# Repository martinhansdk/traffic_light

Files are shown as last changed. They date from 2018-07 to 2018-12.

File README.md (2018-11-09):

Toy traffic light
=================



Firmware for a toy traffic light with intrafred communication between the units.

Features
--------

* The master light sends the timing to the slaves so independent lights remain
  in sync
* Automatic mode follows a preprogrammed timing
* Manual mode allows controlling the light through a button press on the master

Electronics
-----------

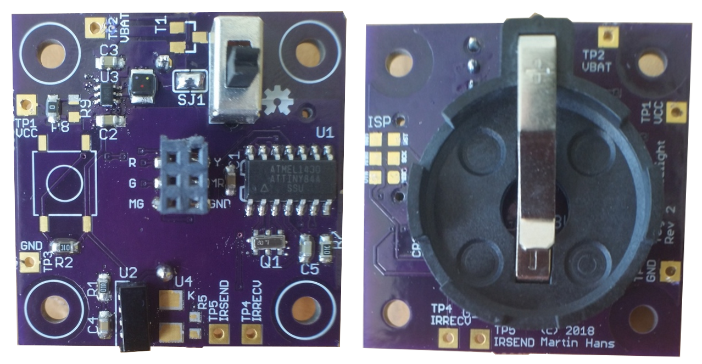
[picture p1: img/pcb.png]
MCU PCB


  * [schematic](pcb/MCU%20board_in_foot_v2.pdf)
  * [BOM](pcb/MCU%20board_in_foot_BOM_v2.html)
  * [EAGLE schematic](pcb/MCU%20board_in_foot_v2.sch)
  * [EAGLE layout](pcb/MCU%20board_in_foot_v2.brd)

The MCU board in the foot of the traffic light contains 

  * a 3V CR2032 battery 
  * an on/off button
  * a boost converter circuit that brings the voltage up to 3.3V
  * an ATTINY84 MCU running at 4 MHz
  * a push button (master only)
  * an IR LED (master only)
  * an IR receive module (slave only)
  * a connector for connecting to the LED board
  * a few test points
  * pads for accessing the ISP port of the MCU using pogo pins

Errata for this version of the board:

  * IRSEND on wrong gpio pin, should be on PB2
  * The IR receiver module has the wrong footprint - it should be the version that looks up
  * The boost converter does not start from CR2032, but works from alkaline
  * Some silk screen is too small
  * Difficult to remove battery from battery holder
  * ISP pins are hard to use. An edge connector would be better.

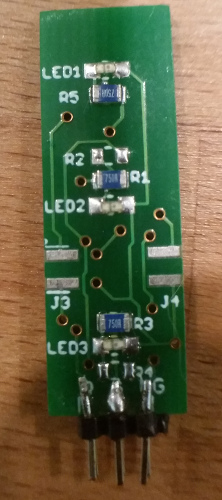
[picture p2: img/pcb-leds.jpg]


  * [schematic](pcb/LEDs_in_top.pdf)
  * [BOM](pcb/LEDs_in_top_BOM.html)
  * [EAGLE schematic](pcb/LEDs_in_top.sch)
  * [EAGLE layout](pcb/LEDs_in_top.brd)

The LED board of the traffic light contains

  * red, yellow and green LEDs with resistors
  * a connector for connecting to the MCU board
  * edge connector for adding another board with pedestrian lights or similar

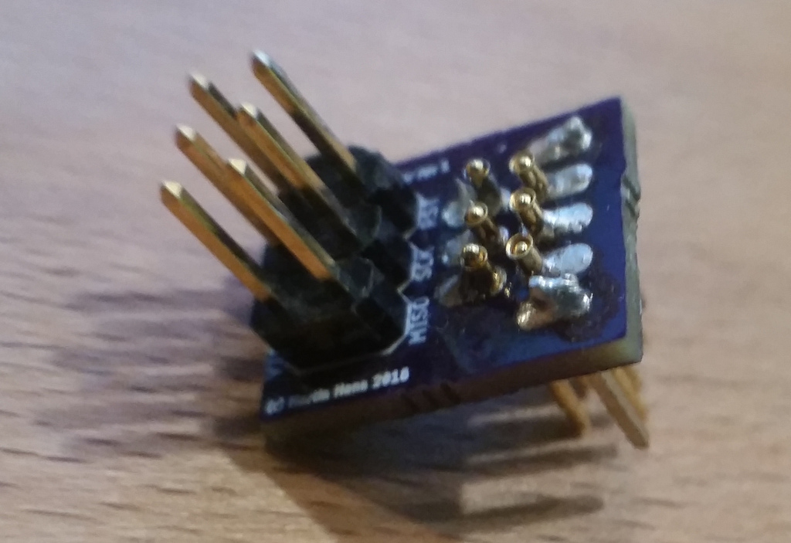
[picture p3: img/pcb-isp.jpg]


  * [schematic](pcb/pogo_pin_programmer_adapter.pdf)
  * [EAGLE schematic](pcb/pogo_pin_programmer_adapter.sch)
  * [EAGLE layout](pcb/pogo_pin_programmer_adapter.brd)

A special purpose pogo pin adapter board brings the footprint of the
ISP header down to a size that is small enough to fit the MCU
board. It also provides access to some debug pins.

This version does not work that well, so I'll probably find a better
solution for the next revision.

Firmware
========

The firmware is written in C.

 * Timer 0 triggers once every 1 ms and drives the light schedule
 * Timer 1 triggers once every 50us and is used by the IR receive code
 * hal/pins.h contains the macros for controlling the GPIO pins in an efficient yet readable manner

For IR communication it uses a library based on
https://github.com/shirriff/Arduino-IRremote. The source of the ATTINY C port
seems to have disappeared from the Internet, so I can't link to it.

The firmware is not feature complete yet. To do:

 * get the IR receive code working
 * implement manual mode
 * use button to select between different programs
 * autodetect master or slave mode
 * use sleep modes

Communication protocol
======================

The communication protocol is RC5 on a 36 kHz carrier frequency. An 18 bit word is sent every time:

 * `data[17]    =    1` : start bit
 * `data[16:10] = 0x5a` : command/address
 * `data[9]     = mode` : 1=manual mode, 0=automatic mode
 * `data[8:0]   = time` : unit is 0.5s

Firmware build instructions
===========================

To build the firmware on Ubuntu or Debian do the following:

    sudo apt-get install gcc-avr binutils-avr avr-libc avrdude
    git clone https://github.com/martinhansdk/traffic_light.git
    
Connect an AVR programmer such as an usbasp to the board. The
programmer has to be set to slow mode and 3.3V operation. Edit the
Makefile to change the programmer type if needed and run
    
    make clean
    make MASTER=1
    make fuse
    make flash
    
To program a slave run the above with `MASTER=0`.

To run the unittests

    make test
    
The unittests execute on the host machine.

Mechanics
=========

The mechanics have not been designed yet, but the traffic light will
be around 10 cm high. The following sketches are from the initial
brainstorming of the concept:

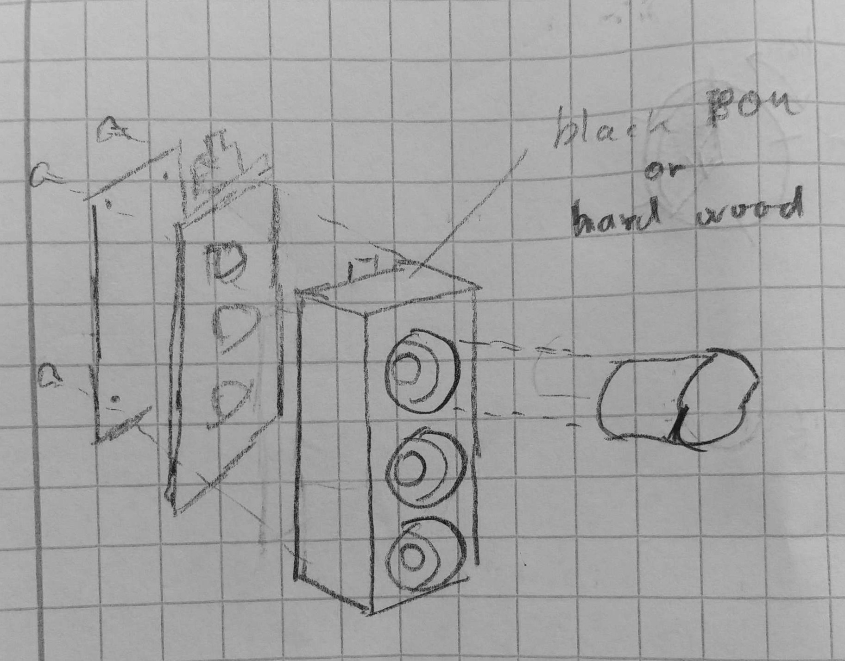
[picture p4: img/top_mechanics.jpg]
Sketch of the top mechanics


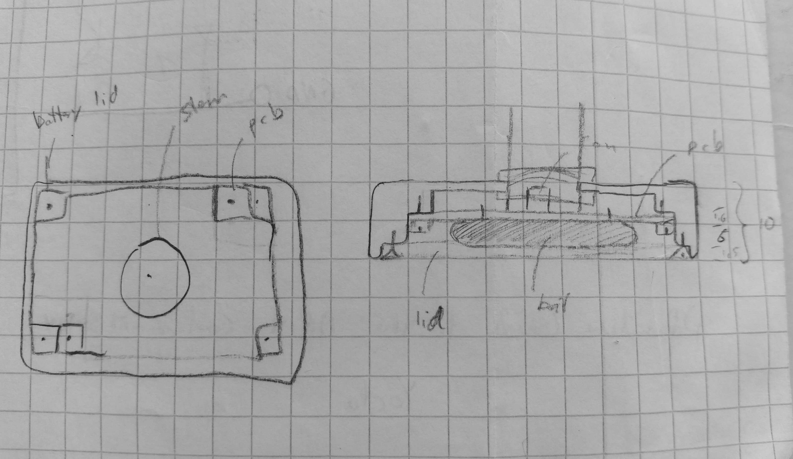
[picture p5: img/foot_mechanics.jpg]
Sketch of the foot mechanics


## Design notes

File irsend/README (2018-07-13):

This is a port of the sending part of the Arduino IRRemote library to
attiny44/attiny84/attiny45/attiny85. It is based on the version at
https://github.com/shirriff/Arduino-IRremote

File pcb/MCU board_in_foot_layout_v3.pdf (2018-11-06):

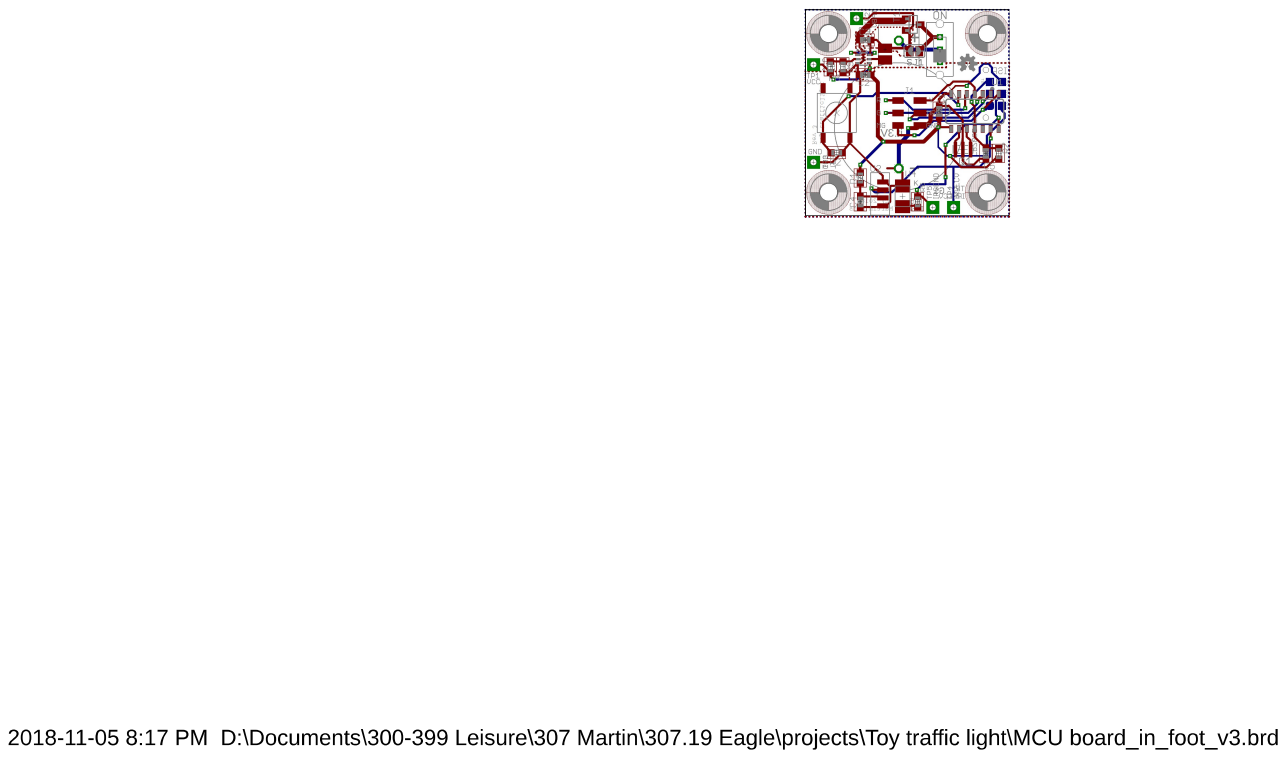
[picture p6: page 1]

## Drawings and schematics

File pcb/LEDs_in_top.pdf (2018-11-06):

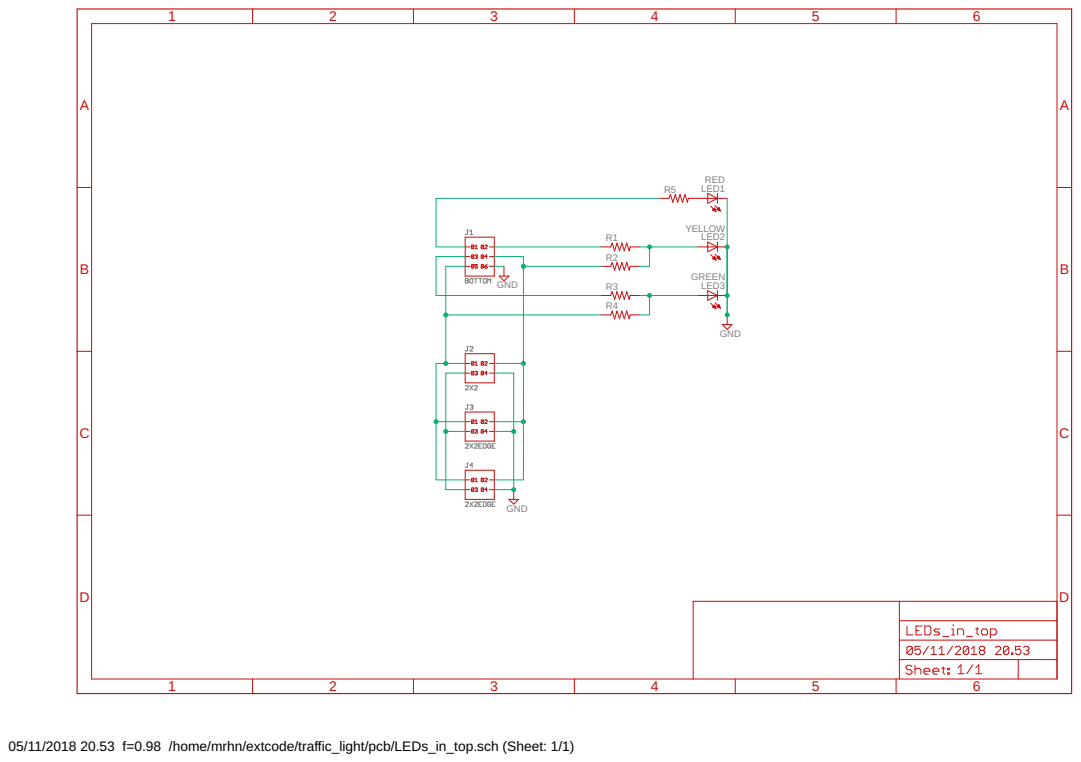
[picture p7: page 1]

05/11/2018 20.53 f=0.98 /home/mrhn/extcode/traffic_light/pcb/LEDs_in_top.sch (Sheet: 1/1)

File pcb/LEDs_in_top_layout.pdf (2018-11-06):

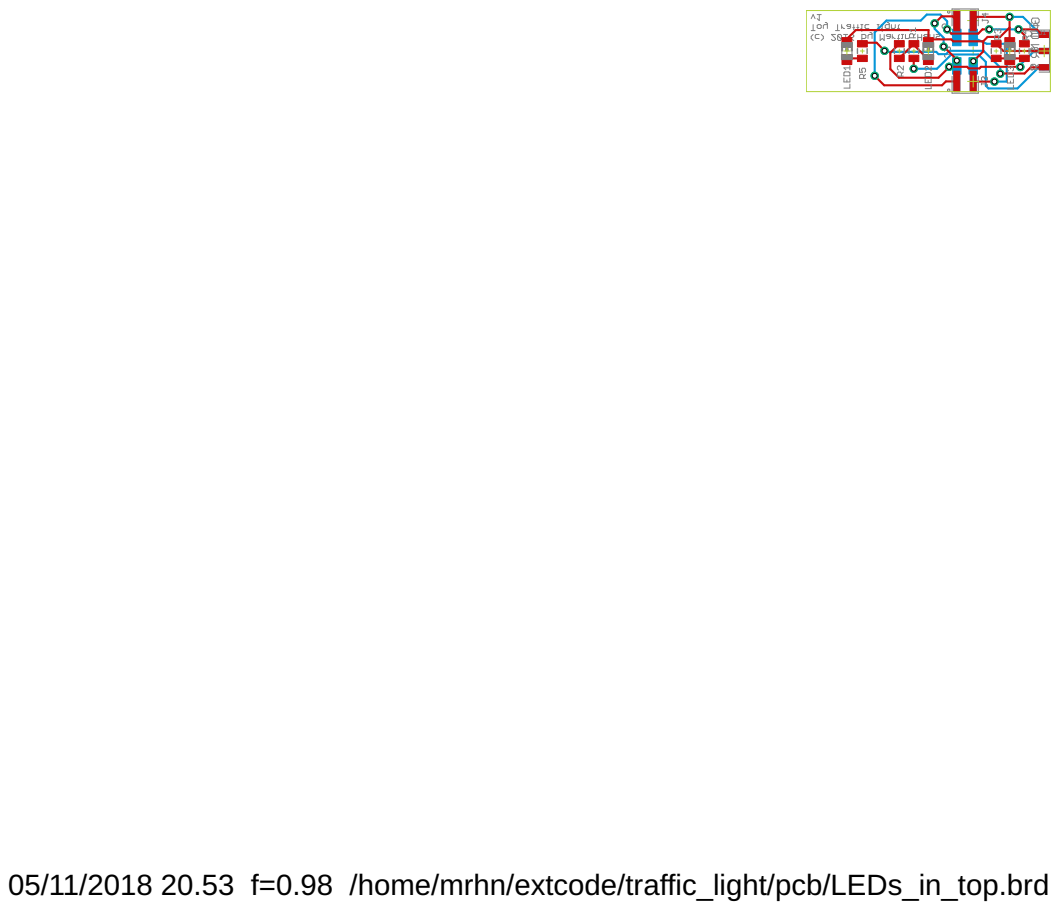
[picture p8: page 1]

05/11/2018 20.53 f=0.98 /home/mrhn/extcode/traffic_light/pcb/LEDs_in_top.brd

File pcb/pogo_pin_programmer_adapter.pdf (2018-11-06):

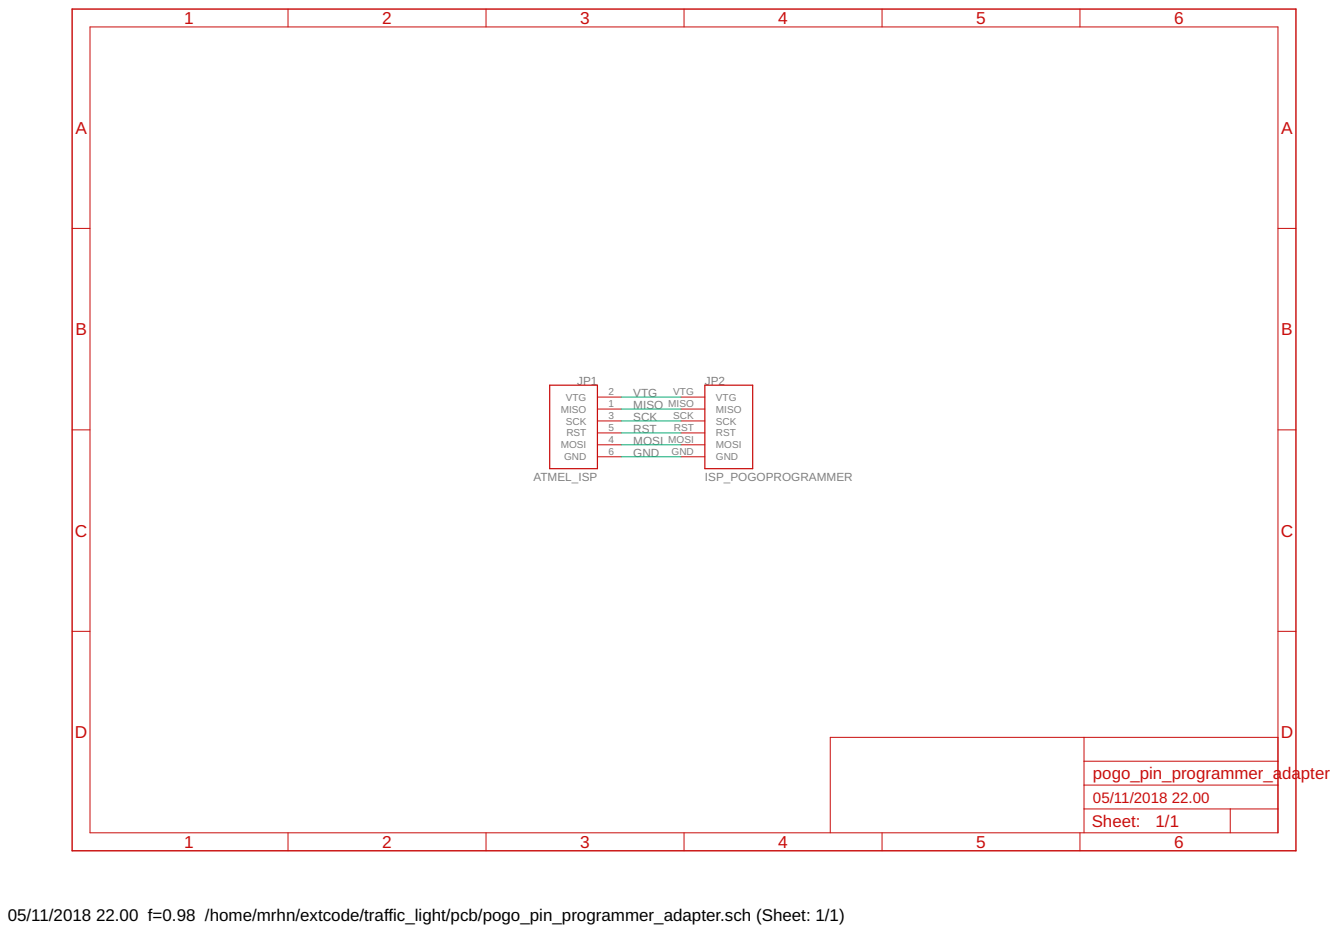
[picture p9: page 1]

05/11/2018 22.00 f=0.98 /home/mrhn/extcode/traffic_light/pcb/pogo_pin_programmer_adapter.sch (Sheet: 1/1)

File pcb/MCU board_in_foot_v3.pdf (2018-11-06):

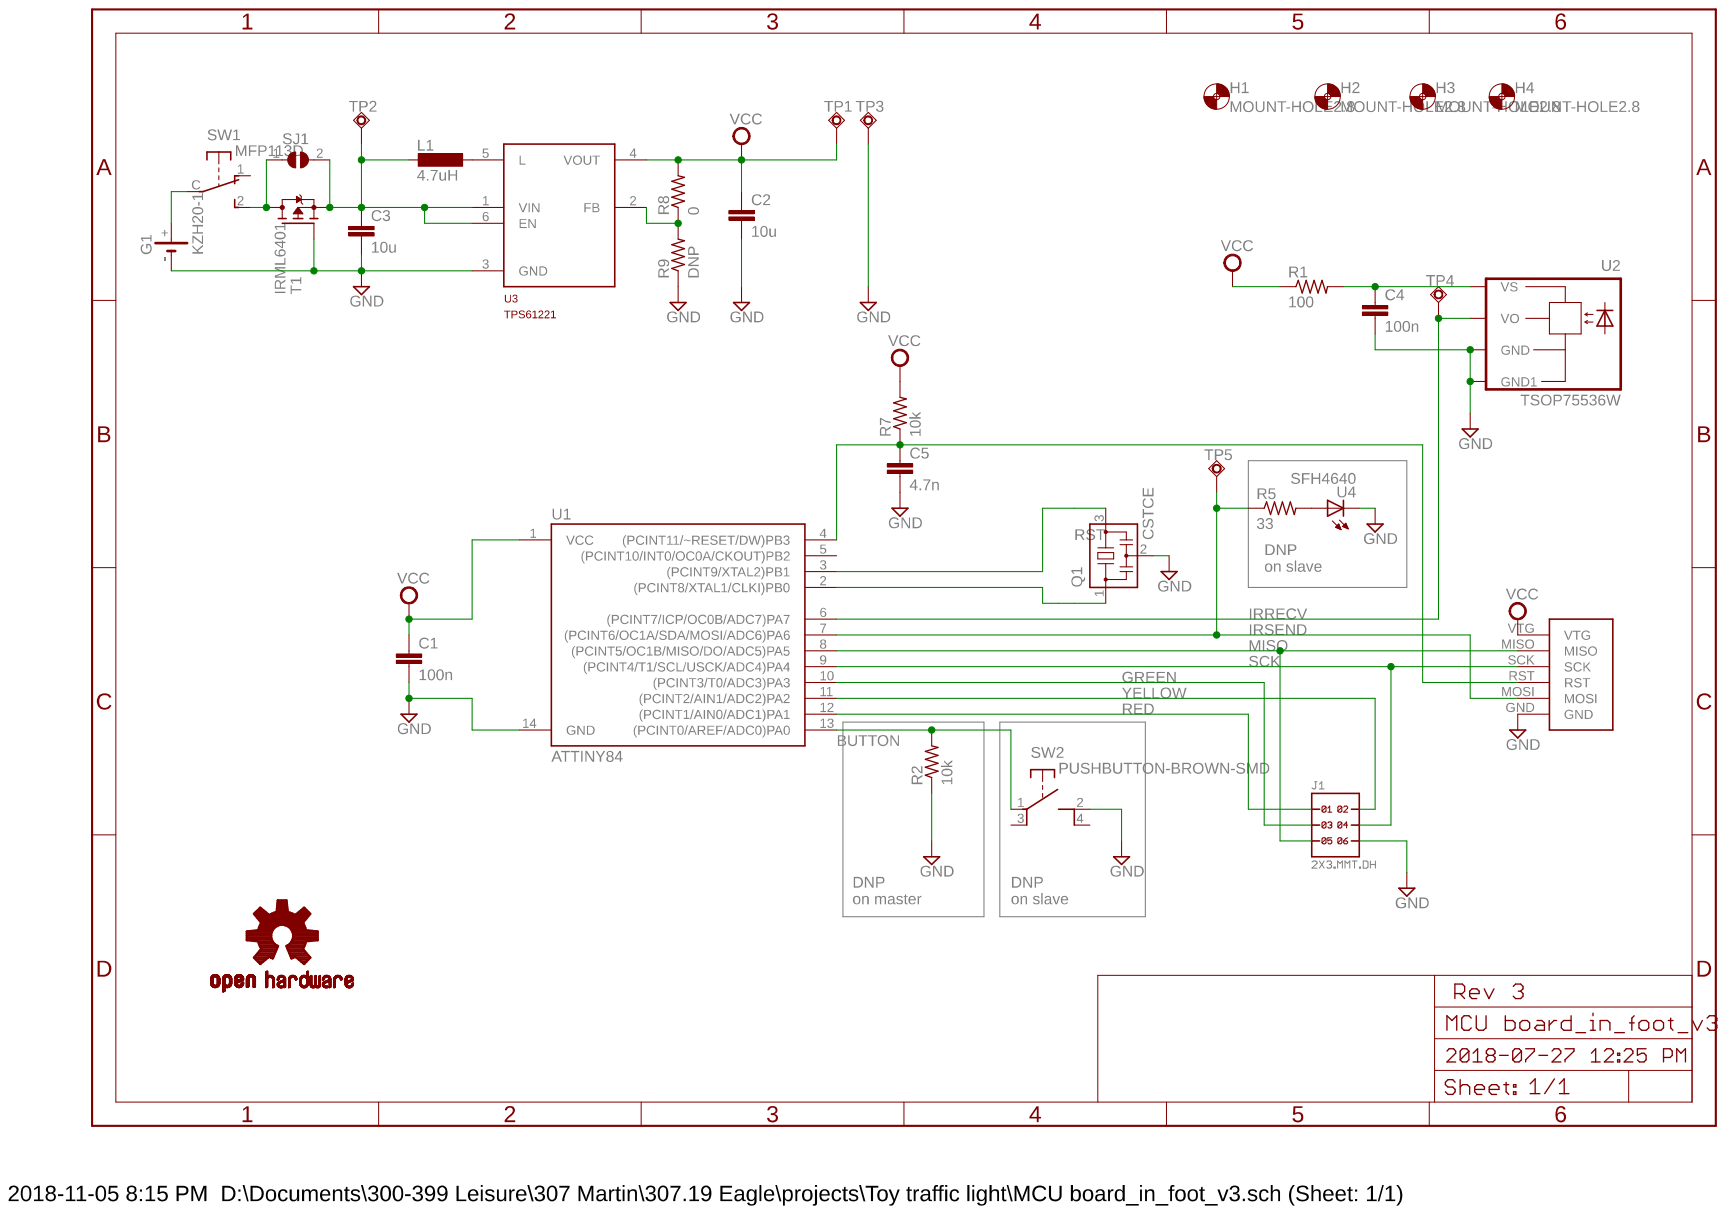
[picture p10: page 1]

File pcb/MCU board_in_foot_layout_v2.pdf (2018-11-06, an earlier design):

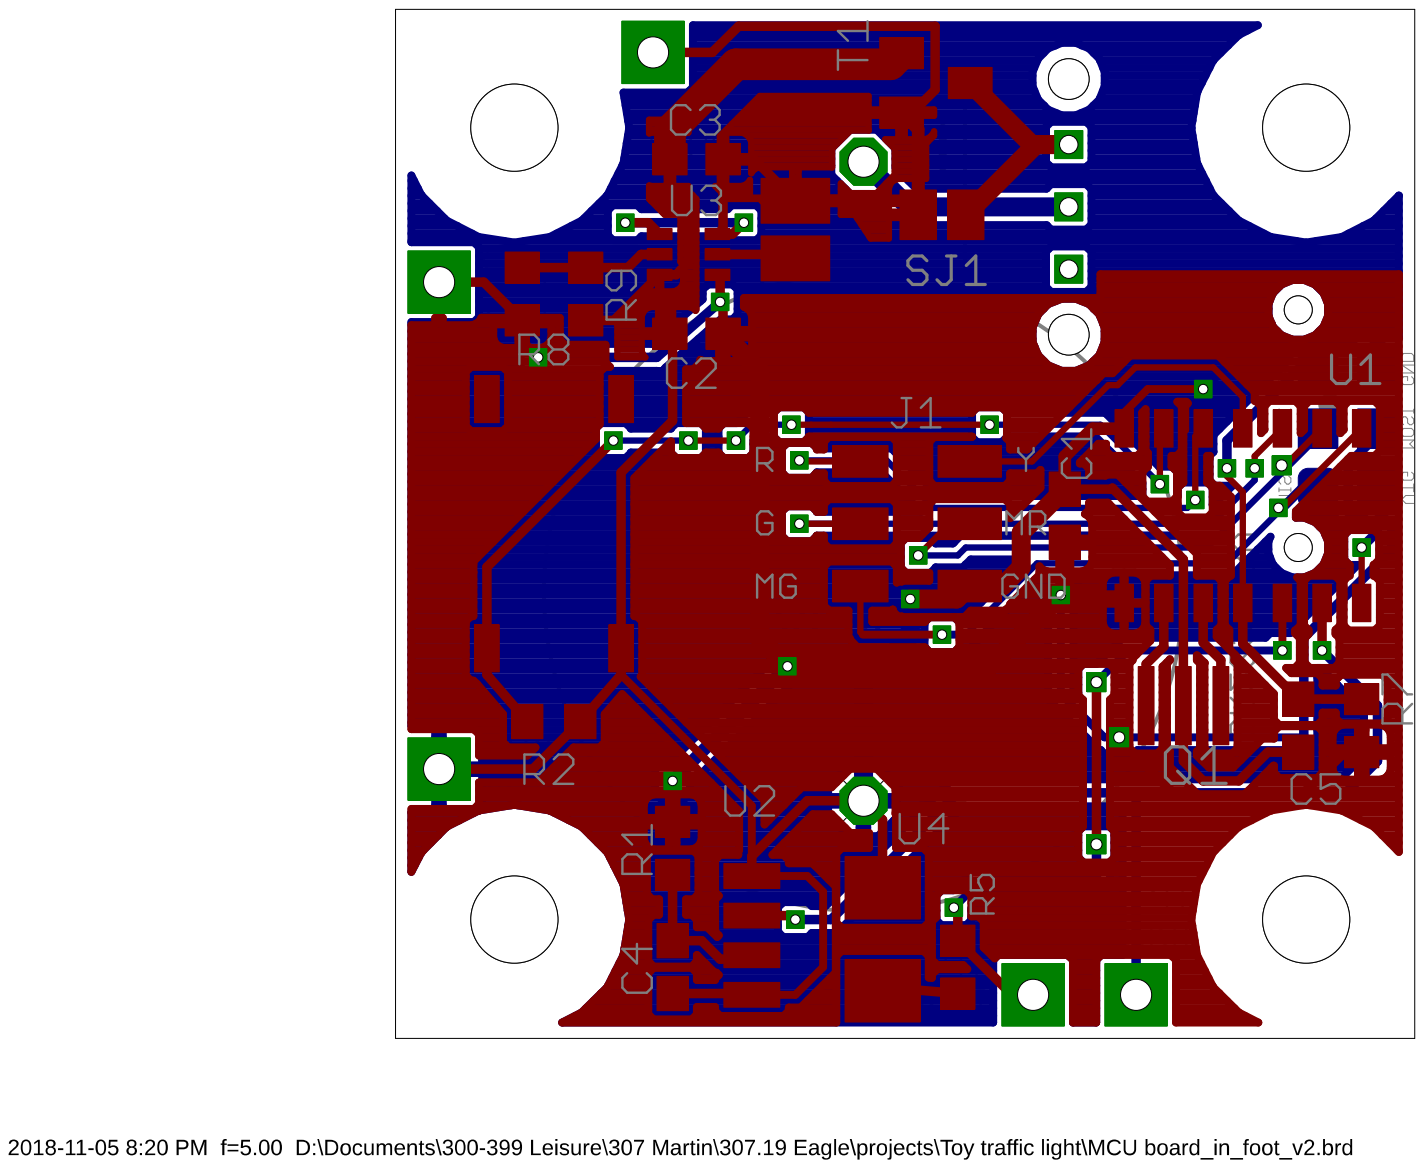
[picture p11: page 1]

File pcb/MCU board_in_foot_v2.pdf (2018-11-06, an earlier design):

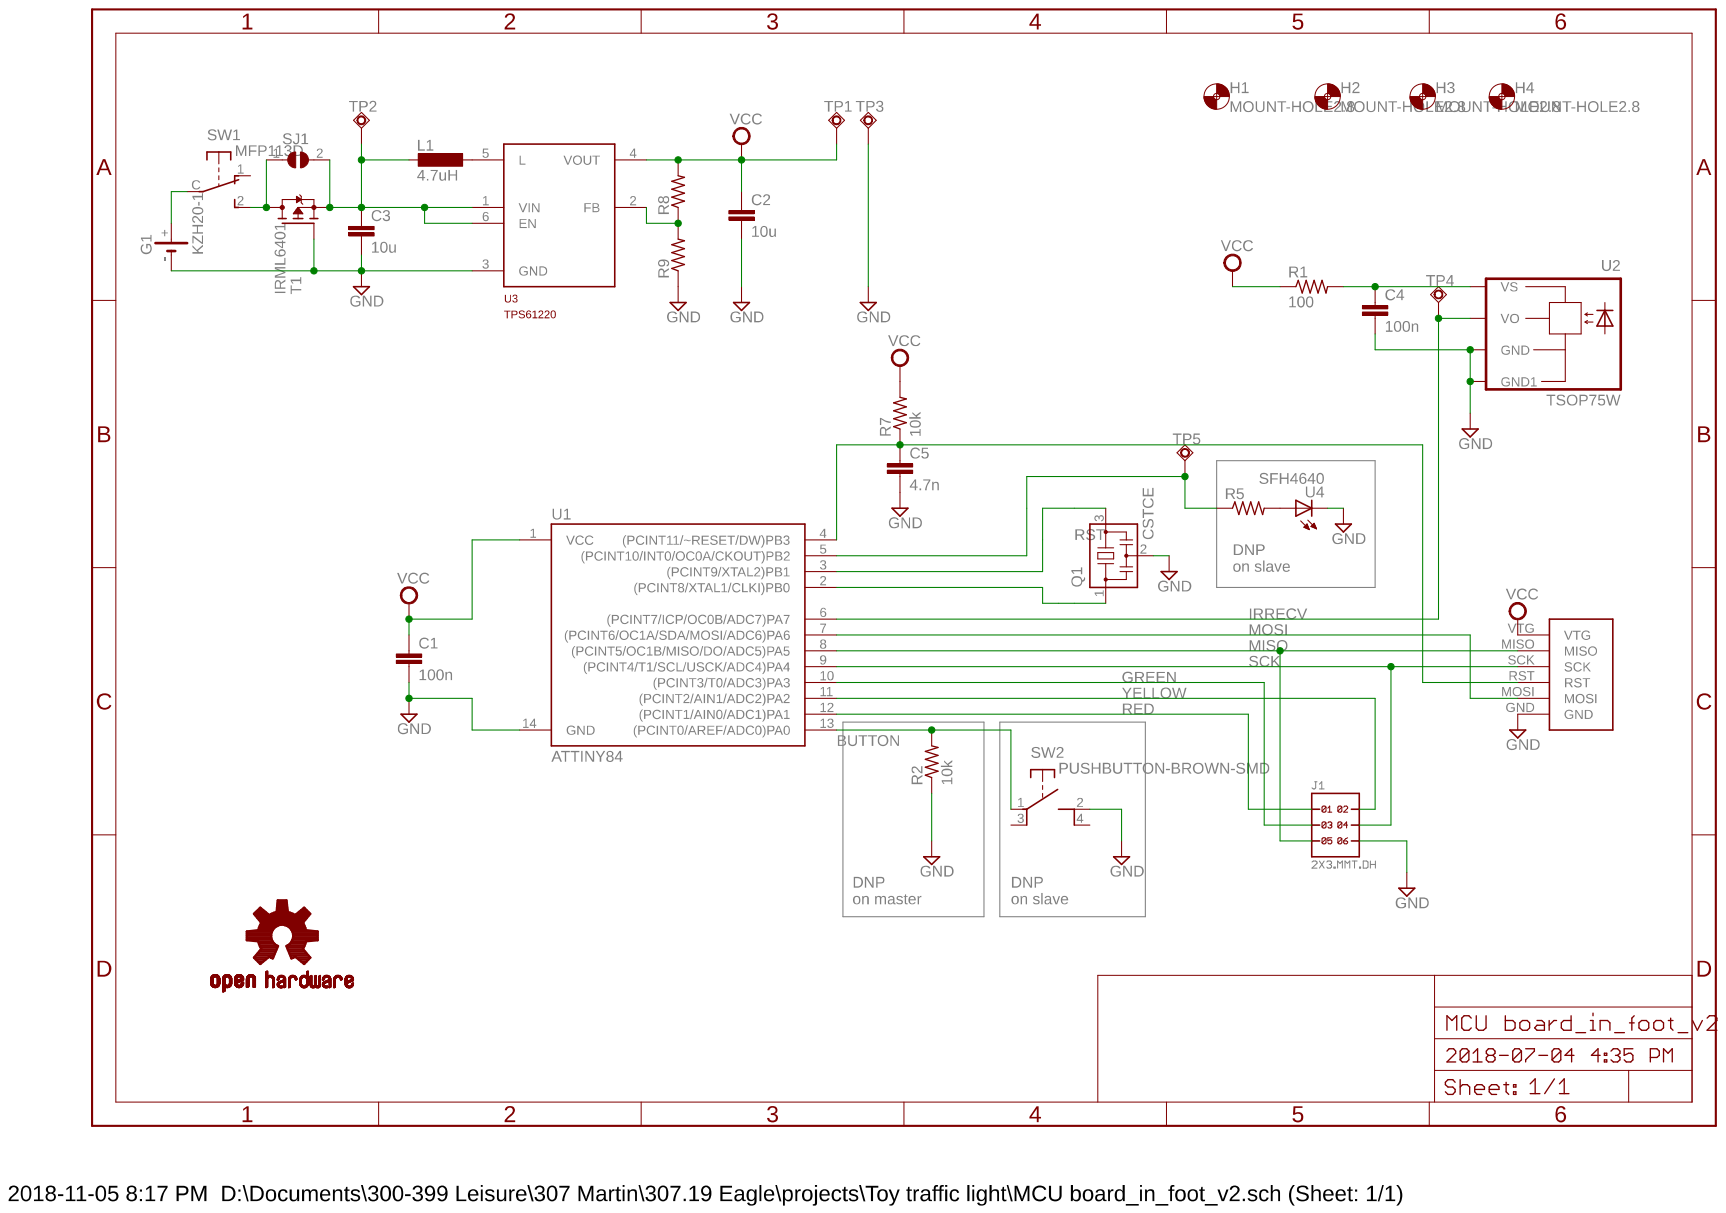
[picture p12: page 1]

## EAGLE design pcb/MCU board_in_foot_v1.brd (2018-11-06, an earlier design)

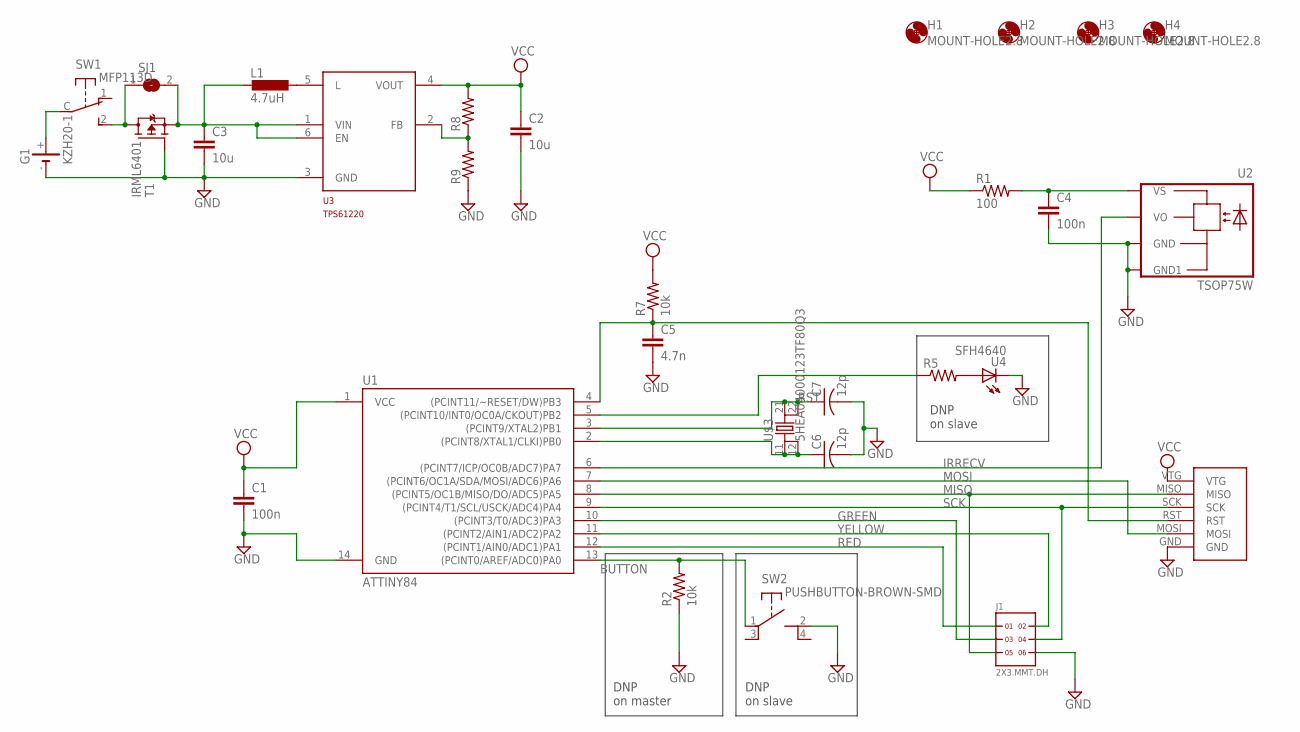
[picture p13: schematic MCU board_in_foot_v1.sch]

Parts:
C1, C4: 100n; 0603-CAP
C2, C3: 10u; 0603-CAP
C5: 4.7n; 0603-CAP
C6, C7: 12p; C0805
G1: KZH20-1
H1, H2, H3, H4: MOUNT-HOLE2.8; 2,8
ISP: ISP_POGOSURFACE; ISP_SURFACE
J1: 2X3.MMT.DH; 2X3_MMT.103.01.X.DH
L1: 4.7uH; EPL2010
R1: 100; R0402
R2, R7: 10k; R0402
R5: R-US_R0402; R0402
R8, R9: RESISTOR0603-RES; 0603-RES
SJ1: SJ
SW1: MFP113D; MFP-SLIDER
SW2: PUSHBUTTON-BROWN-SMD; SMD-SW
T1: IRML6401; SOT23
U1: ATTINY84; SO14
U2: TSOP75W; TSOP75W-SIDELOOK
U3: TPS61220; DCK-R_PDSO_G6
U4: SFH4640; MIDLED
U$3: 5HEA04000123TF80Q3; 10X4.5MM

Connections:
BUTTON: R2.2, SW2.1, U1.13 ((PCINT0/AREF/ADC0)PA0)
GND: C1.2, C2.2, C3.2, C4.2, C5.2, C6.2, C7.2, G1.-, ISP.GND, J1.6, R2.1, R9.1, SW2.2 (S2), T1.1 (G), U1.14 (GND), U2.1 (GND), U2.4 (GND1), U3.3 (GND), U4.K (C)
GREEN: J1.3, U1.10 ((PCINT3/T0/ADC3)PA3)
IRRECV: U1.6 ((PCINT7/ICP/OC0B/ADC7)PA7), U2.3 (VO)
IRSEND: R5.1, U1.5 ((PCINT10/INT0/OC0A/CKOUT)PB2)
MISO: ISP.MISO, J1.5, U1.8 ((PCINT5/OC1B/MISO/DO/ADC5)PA5)
MOSI: ISP.MOSI, U1.7 ((PCINT6/OC1A/SDA/MOSI/ADC6)PA6)
unnamed: L1.P$2 (2), U3.5 (L)
unnamed: SJ1.1, SW1.2 (S), T1.3 (D)
unnamed: C7.1, U1.3 ((PCINT9/XTAL2)PB1), U$3.21, U$3.22
unnamed: R8.1, R9.2, U3.2 (FB)
unnamed: C6.1, U1.2 ((PCINT8/XTAL1/CLKI)PB0), U$3.11, U$3.12
unnamed: C4.1, R1.2, U2.2 (VS)
unnamed: G1.+, SW1.C
unnamed: R5.2, U4.A
RED: J1.1, U1.12 ((PCINT1/AIN0/ADC1)PA1)
RST: C5.1, ISP.RST, R7.1, U1.4 ((PCINT11/~RESET/DW)PB3)
SCK: ISP.SCK, J1.4, U1.9 ((PCINT4/T1/SCL/USCK/ADC4)PA4)
VBAT: C3.1, L1.P$1 (1), SJ1.2, T1.2 (S), U3.1 (VIN), U3.6 (EN)
VCC: C1.1, C2.1, ISP.VTG, R1.1, R7.2, R8.2, U1.1 (VCC), U3.4 (VOUT)
YELLOW: J1.2, U1.11 ((PCINT2/AIN1/ADC2)PA2)

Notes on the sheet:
DNP on master
DNP on slave

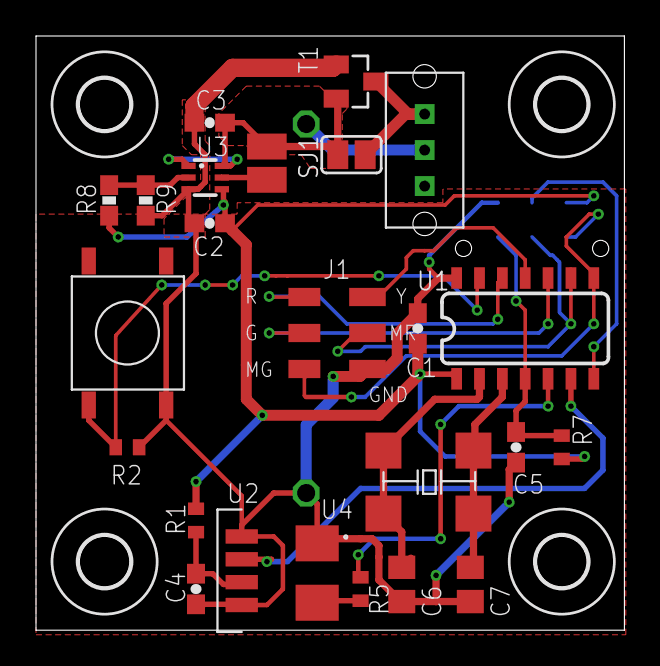
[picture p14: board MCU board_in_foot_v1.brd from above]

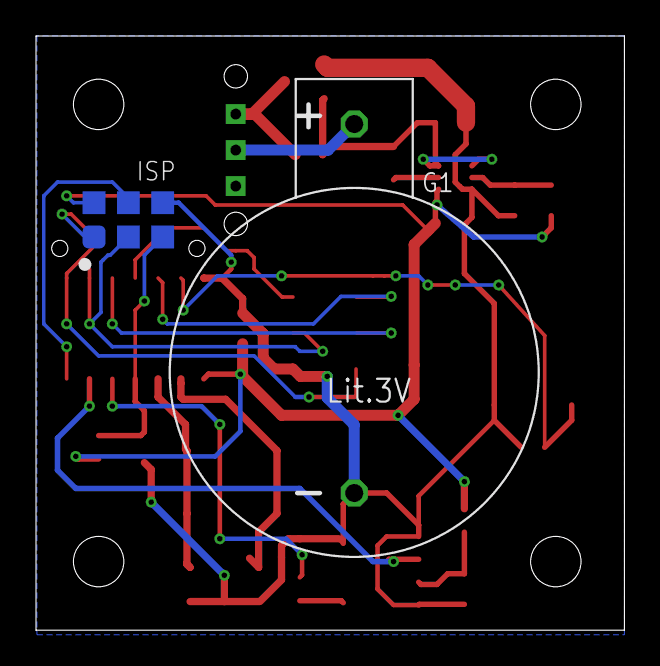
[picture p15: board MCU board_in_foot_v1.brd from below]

Board: 2 copper layers, 32.7 x 33.0 mm, 30 parts (2 on the bottom side), 21 nets.

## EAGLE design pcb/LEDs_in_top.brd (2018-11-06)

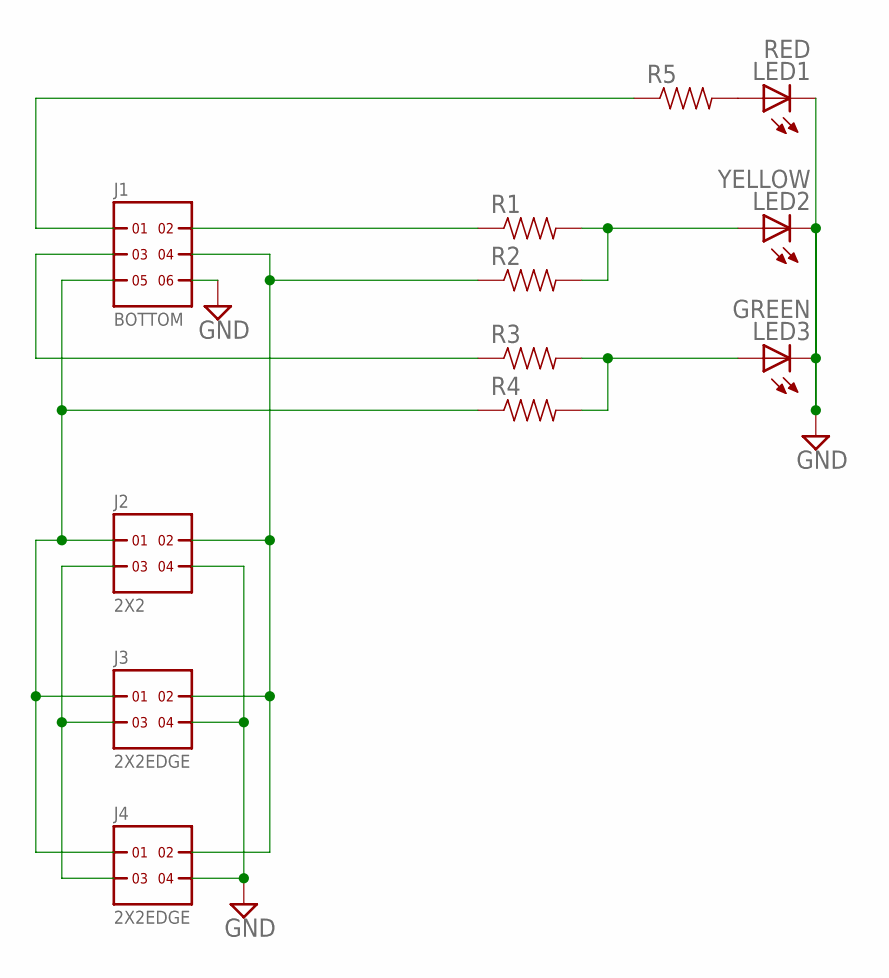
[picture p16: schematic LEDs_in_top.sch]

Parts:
J1: BOTTOM; 2X3-2MM-EDGE
J2: 2X2; 2X2_MMT.103.01.X.DH
J3, J4: 2X2EDGE; 2X2-2MM-EDGE
LED1: RED; CHIP-LED0805
LED2: YELLOW; CHIP-LED0805
LED3: GREEN; CHIP-LED0805
R1, R2, R3, R4, R5: RESISTOR0805-RES; 0805

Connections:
GND: J1.6, J2.4, J3.4, J4.4, LED1.C, LED2.C, LED3.C
GREEN: J1.3, R3.1
MG: J1.5, J2.1, J3.1, J4.1, R4.1
MR: J1.4, J2.2, J3.2, J4.2, R2.1
unnamed: LED3.A, R3.2, R4.2
unnamed: J2.3, J3.3, J4.3
unnamed: LED2.A, R1.2, R2.2
unnamed: LED1.A, R5.2
RED: J1.1, R5.1
YELLOW: J1.2, R1.1

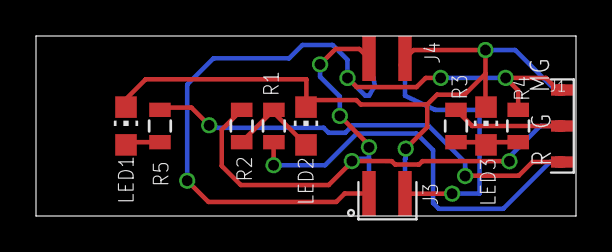
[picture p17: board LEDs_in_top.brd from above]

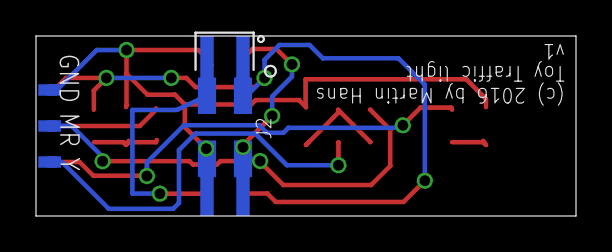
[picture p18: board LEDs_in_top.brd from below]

Board: 2 copper layers, 30.0 x 10.0 mm, 12 parts (2 on the bottom side), 10 nets.

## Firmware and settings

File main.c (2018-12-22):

/******
 Implementation of a toy traffic light.

 timer 0: light scheduling and button debouncing
 timer 1: IR receive and transmit


 Pin assignments:

 PA0: IR activity indicator LED (debug)
 PA1: red LED
 PA2: yellow LED
 PA3: green LED
 PA4: ISP USCK
 PA5: ISP MISO
 PA6: ISP MOSI, IR TX
 PA7: IR RX

 PB0: XTAL1
 PB1: XTAL2
 PB2: NC
 PB3: ISP NRESET
*******/


#ifndef F_CPU
#error F_CPU not defined
#else

#if F_CPU == 4000000
#else
#error F_CPU must be 4000000
#endif

#endif

#ifndef F_OSC
#error F_OSC not defined
#endif


#include <stdbool.h>
#include <stdint.h>
#include <avr/eeprom.h>
#include <avr/io.h>
#include <avr/interrupt.h>
#include <avr/power.h>

#include "messages.h"
#include "schedule.h"
#include "debounce.h"
#include "irrecv/irrecv.h"
#include "irsend/irsend.h"
#include "hal/pins.h"
#include "pin_assignments.h"

volatile int timer_interrupt = 0;
#if MASTER == 1
bool is_master = true;
#else
bool is_master = false;
#endif
bool manual_mode = false;

/**
  light_time contains the global time which is shared by all traffic lights
  The correct state of the lights is computed from this.
  The unit is 1/2 seconds.
*/
#define TIME_UNIT_MS 500
uint16_t light_time = 0;
uint16_t cycle_time = 1;
Schedule schedule;

// P4NOSUBMIT
void save_debug_dword(uint32_t addr, uint32_t word) {
   if(eeprom_is_ready()) {
     eeprom_update_dword((uint32_t*)addr, word);
   }
}


void set_lights(uint16_t light_time) {
  const LightPattern* pattern = currentPattern(&schedule, light_time);

  if(pattern->red) pin_high(RED_PIN); else pin_low(RED_PIN);
  if(pattern->yellow) pin_high(YELLOW_PIN); else pin_low(YELLOW_PIN);
  if(pattern->green) pin_high(GREEN_PIN); else pin_low(GREEN_PIN);
}

void handle_ir_commands(const decode_results *irdata) {

  unsigned long value = irdata->value;
  save_debug_dword(0, value);
  save_debug_dword(4, extract_command(value));
  save_debug_dword(12, MESSAGE_WIDTH);

  pin_toggle(RED_PIN);
  switch(extract_command(value)) {
  case IR_SYNC_CMD:
    extract_sync_message(value, &manual_mode, &light_time);
    save_debug_dword(8, light_time);
    pin_toggle(YELLOW_PIN);
    break;
  default:
    break;
  }
}

bool RawKeyPressed() {
    return get_input(BUTTON_PIN);
}

// timer compare interrupt service routine, called once every 1 ms
uint16_t timer_int_count = 0;

ISR(TIM0_COMPA_vect)
{
  bool button_changed, button_pressed;

  timer_int_count++;
  if(timer_int_count >= TIME_UNIT_MS) {
      timer_interrupt = 1;
      timer_int_count = 0;
  }

  DebounceSwitch(&button_changed, &button_pressed);
}

decode_results irdata = {
    .value = 0
};

int main() {
#if F_OSC == 4000000
  // system clock = oscillator/1 = 4 MHz
  clock_prescale_set(clock_div_1);
#elif F_OSC == 8000000
  // system clock = oscillator/2 = 4 MHz
  clock_prescale_set(clock_div_2);
#elif F_OSC == 16000000
  // system clock = oscillator/4 = 4 MHz
  clock_prescale_set(clock_div_4);
#else
#error Unsupported F_OSC
#endif

  // define schedule
  int i = 0;

  setPattern(&schedule, i++, 2*2, true, true, false); // yellow/red
  setPattern(&schedule, i++, 18*2, false, false, true); // green
  setPattern(&schedule, i++, 4*2, false, true, false); // yellow
  // the duration of the red signal must be just so long that the light pointing
  // in the other direction can cycle through yellow-green-yellow plus a
  // little margin where both are red
  setPattern(&schedule, i, 0, false, false, false); // temporary end marker, remove this when beginning to make intersections
  uint16_t red_duration = cycleTime(&schedule) + 1*2;
  setPattern(&schedule, i++, red_duration, true, false, false); // red
  setPattern(&schedule, i, 0, false, false, false); // end marker

/*
  setPattern(&schedule, i++, 1*2, false, true, false); // yellow
  setPattern(&schedule, i++, 1*2, false, false, false); // off
  setPattern(&schedule, i, 0, false, false, false); // end marker
*/

  cycle_time = cycleTime(&schedule);


  // Set LED ports to output
  set_dir_out(RED_PIN);
  set_dir_out(YELLOW_PIN);
  set_dir_out(GREEN_PIN);

  pin_high(RED_PIN);
  pin_high(GREEN_PIN);
  
  // initialize timer0, trigger compare interrupt once every 1 ms
  TCCR0A = 0x02;      // Clear Timer on Compare Match (CTC) mode
  TIFR0 |= 0x01;      // clear interrupt flag
  TIMSK0 = 0x02;      // TC0 compare match A interrupt enable
  TCCR0B = 0x03;      // clock source CLK/64, start timer

#if F_CPU == 4000000
  OCR0A  = 62;        // number to count up to
#else
#error Unsupported F_CPU
#endif

  setup_irrecv();

  sei();             // enable all interrupts

  while(1) {
      // wait until timer isr was run
      while(true) {
        if (irrecv_decode(&irdata)) {
          handle_ir_commands(&irdata);
          irrecv_resume();
        }
        if(timer_interrupt) break;
      }
      timer_interrupt = 0;

      light_time++;

      if(light_time >= cycle_time) {
        light_time %= cycle_time;
      }

      if(is_master) {
        //irsend_sendRC5( make_sync_message(manual_mode, light_time), MESSAGE_WIDTH); P4NOSUBMIT
        irsend_sendRC5( make_sync_message(manual_mode, 0x155), MESSAGE_WIDTH);
        save_debug_dword(0, make_sync_message(manual_mode, 0x155));
        save_debug_dword(4, make_sync_message(manual_mode, 0x155) & 0x3ffff);
      }

      if(is_master) // P4NOSUBMIT
      set_lights(light_time);
  }
}

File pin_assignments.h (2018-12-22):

#define BUTTON_PIN A,PA0
#define IR_SEND_PIN A,PA6
#define RED_PIN A,PA1
#define YELLOW_PIN A,PA2
#define GREEN_PIN A,PA3
#define IR_RECEIVE_PIN A,PA7

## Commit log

2015-02-06 port the Arduino version to bare bones C
2015-02-06 add debounce logic for button - not debugged, just added to get an idea of code size
2015-02-06 adjust timer interrupt to trigger every 1 ms
2015-02-06 make timer 0 interrupt work and fix LED output
    [main.c]
2015-02-06 fix schedule time wrap around
    [main.c]
2015-02-06 switch to 4MHz external clock
2015-02-09 nicer way of defining pin assignments
    With these macros, it is possible to define which port and pin
    is used for a function in one place. Previously, if a function
    was moved to a pin on a different port, it was necessary to
    hunt down all the places the pin was referenced and change
    the port register. The macros take care of this now.
2015-02-27 Switch to internal RC clock (calibrated)
2015-03-01 Fix that "make clean" would delete debounce.c
    Switch to internal RC oscillator, system clock at 4 MHz.
    Master sends time and mode every 500ms.
    [main.c]
2018-07-17 Change pin assignment to match the PCB
2018-07-25 Switch to usbasp as programmer and allow selecting master/slave from makefile.
2018-11-06 Properly document the current state of the project and add PCB files
    [LEDs_in_top.brd, LEDs_in_top.sch, MCU board_in_foot_v1.brd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]
2018-11-09 Fix construction of the command word.
    Some of the bit shifting math did not work because an int is 16 bits
    and some of the bit shifting math ended up shifting the data out of
    this range.
    [main.c]
2018-11-09 Fix wrong gcc command line switch

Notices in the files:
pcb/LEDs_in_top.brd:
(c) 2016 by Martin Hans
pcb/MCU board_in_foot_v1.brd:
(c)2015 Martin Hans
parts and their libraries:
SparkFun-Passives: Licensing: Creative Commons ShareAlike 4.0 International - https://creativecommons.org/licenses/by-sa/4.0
